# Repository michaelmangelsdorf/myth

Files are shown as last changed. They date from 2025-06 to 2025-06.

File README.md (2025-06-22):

### Intro

This is my successor project to [Sonne8](https://github.com/michaelmangelsdorf/Sonne8), a discrete micro-controller built using about one-hundred 74HC series logic chips, some CMOS memory and passive-components only. It runs about 1 million instructions per second on a four-layer PCB.

A demonstration video in the other repo shows the controller board with a companion I/O-board I designed stacked on top of it.

In the video, it loads a program for multiplying two numbers from a serial EEPROM running a native SPI implementation. It then computes the result and displays it on the I/O boards 7-segment display.

The new project over here will help me explore a specific, stable version of the CPU a little more and write software for it, before developing more hardware.

The schematics have been stripped of everything I thought wasn't essential, so it's a bit easier to read. In other words, although it's possible to load the schematics file into KiCad, its intended use is only for reference.

The C file is also for reference. It shows the intended workings of the CPU. For a more detailed description of this microcontroller read "spec.md".

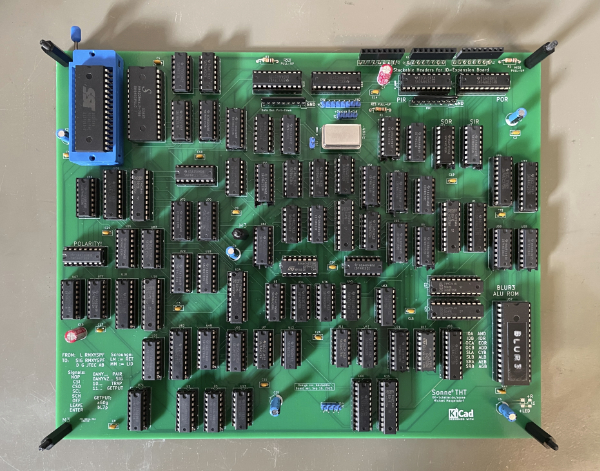
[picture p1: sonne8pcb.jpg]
PCB with working Sonne8 micro-controller


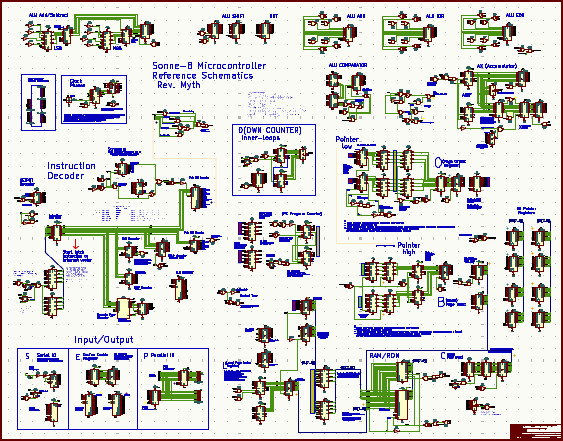
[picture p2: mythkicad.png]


The component count is now higher than for the prototype, because in this project I've implemented the ALU (top and top-right in schematics) in discrete logic, where it used to be just look-up tables in a big PROM.

### Status

There is now a command-line tool (`my`) for exploring Myth. It includes an assembler. The tool is documented in the [specification](https://github.com/michaelmangelsdorf/myth/blob/main/spec.md) file.

### Code Example

Here is an example of a native multiplication routine which multiplies the two 8-bit numbers in the accumulator, leaving the accumulator with the 16-bit result (high-order in A). The listing is the output of the assembler using `my -la`.

    ADDR:  OBJCODE:                  LIN:  SOURCE:
                                     0001  
                                     0002  (Multiply 4x7)
    0000:  84 04 84 07 80 03         0003  fa 4, fa 7 - fc >MUL8. ; Sets A to 7, X to 4 and calls mul8
    0006:  8C 06                     0004  @idle fj <idle         ; my-tool stops at 64k cycles
                                     0005                         ; Check the result using: "my -p"
                                     0006  
                                     0007  ; Multiply A times X, result in A:X
                                     0008  ; A:X accumulator acts as a two-element push-down stack when writing to A
                                     0009  ; Both regs are the implied ALU operands, primary result in A, secondary in X
                                     0010  
                                     0011  ; Using page 3: "my"-tool uses p1 for persisting regs, p2 as IO-buffer
                                     0012  
                                     0013  3@MUL8
    0300:  68                        0014      a1          (Save multiplicand into L1 - turns into low order result)
    0301:  17 6B                     0015      xa a4       (Save multiplier into L4)
    0303:  84 00 69                  0016      fa 0, a2    (Set high-order result to 0, keep in L2)
    0306:  85 07                     0017      fd 7        (Initialise loop counter, 8 bits to process)
                                     0018      @loop
                                     0019          fa b0000_0001, 1a AND  (Check LSB of multiplicand)
    030C:  8E 12                     0020          fz >a                  (Skip if zero)
    030E:  63 61 1D 69               0021              4a 2a ADDC a2      (Add multiplier to high order result)
                                     0022          @a
                                     0023          1a SHR, a1             (Shift low-order result right)
    0315:  61 1B 69                  0024          2a SHR, a2             (Shift high-order result right, LSB saved to X)
    0318:  17 60 15 68               0025          xa 1a IOR, a1          (Carry high-order LSB into low-order MSB)
    031C:  8B 08                     0026      fw <loop
    031E:  60                        0027      1a          (Push low-order result)
    031F:  61                        0028      2a          (Push high-order result)
    0320:  05                        0029      RTS

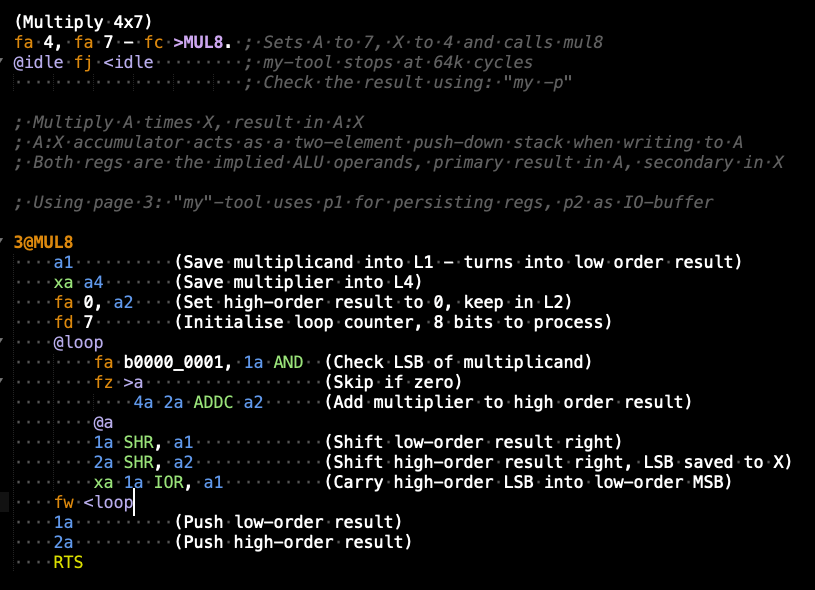
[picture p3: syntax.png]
Source
Source Code  of the multiplication routine in Sublime text with syntax highlighting.

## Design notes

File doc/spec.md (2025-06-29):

## Myth CPU/Micro-Controller
## OVERVIEW

Myth is an educational 8-bit CPU with a reduced, but hopefully enjoyable feature set. It has no microcoded complex instructions, but care has been taken to allow for practicable programming that should be intuitive to the assembler programmer.

The project is based on an earlier prototype, built successfully using just under 100 74HC series chips, some CMOS memory and passive components.

Published schematics and documentation of the earlier project, including the design files for the final PCB production run at JLCPCB are on GitHub:
https://github.com/michaelmangelsdorf/Sonne8

## PART 1

### Basic CPU

#### Power-up and Reset

When the CPU is reset, registers L (stack frame pointer), C (program page index), PC (program offset) and the BUSY flag (disable interrupts) are set to zero, and the first instruction is fetched from address C:PC. PC is then incremented for the next instruction fetch, and so on.

#### Accumulator and ALU

An accumulator with two registers (A and X) feeds into an Arithmetic Logic Unit (ALU), computes a result, then overwrites A and, in some cases, X with the results.

The primary result (the sum of both registers, for instance) is stored in A, the secondary result (carry bit of the sum) is stored in X.

When writing a value into A (instructions _A and GETA), the accumulator functions as a two-element push-down stack: The old value of A is saved into X before overwriting it with the new value. X can be saved into A with the XA instruction.

X cannot be read or written directly.

Here is an example that demonstrates the use of the ALU in conjunction with the accumulator:

    ; F_ fetches a literal and places it into whatever _ is
    
    FA 4  (Pushes 4 onto the accumulator stack AX)
    FA 5  (Pushes 5)
    
    (A is now 5, X is 4)
    
    ADDC  ; Add A and X; secondary result/side effect:
          ; carry bit in X
    
    (A is now 9, X is 0)
    
    SHR   ; Shift A right; secondary result/side effect:
          ; previous low order bit as 0 or 80h in X
    
    (A is now 4, X is 1)
    
    AGX   ; Produce flag: A greater than X, no side effect
    
    (A is FFh - true, X is 1 - unchanged)

The ALU can run the following opcodes:

     0 NOT   Set A to one's complement of A, X unchanged
     1 ALX   Flag (A<X) in A (255 if true, 0 if false), X unchanged
     2 AEX   Flag (A==X) in A (255 if true, 0 if false), X unchanged
     3 AGX   Flag (A>X) in A (255 if true, 0 if false), X unchanged
     4 AND   Set A to (A AND X), X unchanged
     5 IOR   Set A to (A OR X), X unchanged
     6 EOR   Set A to (A XOR X), X unchanged
     7 XA    Set A equal to X, X unchanged
     8 AX    Set X equal to A
     9 SWAP  Swap A and X
    10 SHL   Shift A left, result in A, set X to previous MSB of A as LSB (0 or 1)
    11 SHR   Shift A right logically, result in A, set X to previous LSB of A as MSB (0 or 80h)
    12 ASR   Shift A right arithmetically, set X to previous LSB of A as MSB (0 or 80h)
    13 ADDC  Add A to X, result in A, CARRY bit in X (0 or 1)
    14 ADDV  Add A to X, result in A, OVERFLOW flag in X (255 if OVF, else 0)
    15 SUBB  Subtract A from X, result in A, BORROW bit in X (0 or 1)

#### Memory Layout

Memory is accessed as 256 pages of 256 bytes each (64k).

A memory address is composed of a page index (high order address byte) and an offset (low order address byte) within that page. For example address 0x6502 has a page index of 0x65 and a byte offset of 0x02.

##### Offset Registers

There are only two offset registers and they are the only means of setting address offsets in this design, so must be used for directly accessing memory.

For data memory access, the byte offset in the offset register (O) is used, and the byte offset for fetching instructions and literals is stored in the program counter register (PC).

There are instructions that access memory with implied offsets, however.

##### Page-Index Registers

There are four page-index registers: B for Base, C for Code, K for Key, and L for Local.

###### Register B

For data memory access, the base register (B) is used together with O as the memory pointer to the address where read or write operations occur.

The 16-bit value B:O is called the base pointer. The base pointer is the only means of composing complete 16-bit addresses (pointers) directly.

###### Register C

When code is running, the program counter register (PC) holds the byte offset of the current instruction in memory. The page number where this offset applies is stored in C (Code).

###### Register K

This is an amenity register that can be set to B using the KEY instruction. It is used in conjunction with the PAIR transfer target xK, an effect register. When writing into xK, the written value is stored in O, and B is set to K.

The intended use for this instruction is to provide a shortcut:

    ;Load a system variable (MYVAR) from a table in page 2
    fb 2 KEY (Set key page-index)
    ...
    fk MYVAR ma (Set base pointer to the MYVAR location and read into A)

###### Register L

The purpose of the L (local) page index register is to provide single page stack frames for subroutines. During subroutine calls, the page index in L is decremented, so that memory reads and writes using the L page index transparently access memory which is local to the currently running subroutine. When the subroutine returns, the page index in L is incremented, so that the previous stack frame (or L page) is restored to the calling subroutine.

#### GETPUT Instructions and Stack Frames

Instructions of type GETPUT complement the behaviour explained in the section on L. GETPUT instructions have mnemonics that consist of a digit and a letter. The letter names one of the allowed registers for this type of instruction: B, O, A, or D. The letter is a digit between 1 and 8, used as a short-hand to reference offsets 0xF8 to 0xFF in the local page (page index L). These memory locations are also referred to as L1 to L8. By means of the GETPUT instructions, L1 to L8 become quick-access memory locations that can be used as local variables within the current stack frame.

The position of the digit relative to the letter determines the direction of the data move. For example: 1a transfers the memory content at offset 0xF8 into register A. And d5 transfers register D (down-counter) into memory at offset 0xFC of the local page.

The local-page index can be manually decremented using ENTER, and manually incremented using LEAVE.

#### PAIR Instructions and Effect Registers

Data move instructions of type PAIR have mnemonics that consist of two letters, one for the source, followed by one for the target of the data move. For example, in order to write register B into A, there is an instruction with the mnemonic "ba".

Some registers are "conventional" data registers, such as B and A, which correspond to physical registers, but there are also EFFECT registers, which source or distribute data indirectly, or trigger conditional actions. One of them is the F register (fetch). It extracts the next byte in the instruction stream, and then skips to the next instruction.

Example: "fa" fetches the byte following the current instruction in memory, and stores it into A. It then increments the program counter by 1 so that the next instruction is fetched instead of the literal.

#### Intrapage Control Flow and D Register

Branching inside of the current code page (page index C) is controlled by writing into the five effect registers J (Jump), W (While), H (Hot/Not zero), Z (Zero), or N (Negative).

By writing a branch offset into J, the program counter is set to this new offset without condition. Writing to H loads the PC with the new offset only if register A (Accumulator) is non-zero ("hot"). Writing to Z loads PC with the new offset only if A is zero. W (while) works in conjunction with the D (down-counter) register; when a branch offset is written into W, PC is loaded with the new offset only while/if the D register is non-zero. Then, in either case, the D register is decremented.

#### Interpage Control Flow and TRAP Instructions

On power-up and reset, registers C and PC are set to zero and the first instruction is fetched from address C:PC.

Branching to code in a different page is done by writing into one of the effect registers C (call), by executing a return instruction (RTS or RTI), the COR (coroutine) instruction, or executing a TRAP instruction.

TRAP instructions have immediate opcodes that encode a target page-index for a call. When executed, an implicit subroutine call to this encoded page-index occurs within a single instruction. A TRAP to page 0 sets the BUSY flag and disables interrupts. The BUSY flag is cleared by executing RTI. Trap calls must be left by executing RTI (Return from Interrupt)!, since they are using another pointer (IA) instead of B:O for saving and restoring the return address.

When executing RTS, the code page index register C is loaded with the value in B (base), the program counter register PC is loaded with the value of register O (offset), and the local-page index in register L is incremented.

When executing RTI, the C:PC pair is loaded from the IA amenity pointer, and the local-page index in register L is incremented.

While executing a trap or when writing a target page-index into the effect register C (call), the program counter is set to 0 (!) and the target page index is loaded into C, so that execution in the target page always starts at offset zero, the page "head".

When writing a target page index into C (call), the previous value of C is first saved into B (base), and the value of PC is saved into the O (offset) register before PC is set to zero, so that the called subroutine can save this information in order to return to the caller.

#### PAIR Memory access - Effect Register M

Writing into M (xM) stores the value into memory at page index B offset O. Conversely, reading from M (Mx) transfers the value stored into that memory cell into the target of the PAIR instruction. There are no other memory transfer instructions besides xMx, the GETPUT instructions, and Fx.

#### Scrounged PAIR opcodes

Inherent NOP instructions such as BB, OO, AA, and DD, and impractical instructions such as FM and MM (same-cycle memory load-store) are repurposed ("scrounged"), and their respective opcodes execute different instructions.

	FM routed to: KEY (Copy B into K)
	MM routed to: CODE (set B:O to C:PC)
	BB routed to: LOCAL (set B:O to L:0xF7 - "L0")
	OO routed to: LEAVE (increment L)
	AA routed to: ENTER (decrement L)
	DD routed to: INC (increment A)
	SS routed to: DEC (decrement A)
	PP routed to: EA (Copy E to A)

#### B:O Pointer Register (BOPs) and Amenity Pointers

As mentioned, registers B (base) and O (offset) form a 16-bit pointer for memory access. The xU (update) instruction is used to add an 8-bit signed number to this pointer for doing address arithmetic.

There are four 16-bit amenity registers into which the B:O pointer can be saved, or from which it can be loaded in a single instruction (instruction group BOP). For instance: BOP1 stores the B:O pointer into P1, and P1BO stores P1 into B:O.

The fourth amenity pointer (P4 => IA) is reserved for trap and interrupt operation. See the note on usage conventions for these pointers in the "Programming" section.

#### Interrupts

An external device can make an interrupt request (IRQ) by asserting the IRQ signal.

At the beginning of each instruction cycle, the CPU checks whether an Interrupt must be serviced. There are two conditions which prevent an interrupt from being serviced by the microcontroller during a given instruction cycle. Firstly, when the CPU is running code within page 0, for example just after RESET, and secondly when the BUSY flag is set.

If the BUSY flag is not set, and the page index in C is not zero, the CPU injects a "fake" TRAP call instruction to page 0, instead of fetching a proper instruction opcode. By entering page 0, an interrupt service routine in page zero at address-offset 0 is run.

To re-enable interrupts, the software must execute an RTI instruction (Return from Interrupt). RTI behaves like RTS (Return from Subroutine), but clears the BUSY flag and uses a separate pointer register (IA) to save/restore the return address. As long as the BUSY flag remains set, downstream service routines or other code will not be interrupted by interrupts.

The interrupt service subroutine once it returns resumes execution at the point in code where the interrupt occurred.

You can manually set BUSY by executing TRAP 0. Only this instruction will work, other calls to page 0 do not have this side effect.

## PART 2 - I/O Functionality (Dedicated Registers and Instructions)

#### Device Selection

The CPU can control serial and parallel communication with external components. This is facilitated by dedicated hardware-registers and instructions.

##### E (Enable) register

The 8-bit E register is used to control the select state of devices attached to the serial or parallel bus lines. To this end, the register is divided into two independent four-bit groups for device selection.

Each four-bit group (L for the low-order, H for the high-order) drives a 4-to-16 line decoder, which maps the bit pattern encoded by that group to 1 of 16 possible, mutually exclusive select signals (SL0-15 and SH0-15) per group.

###### Special Purpose Selectors

Select signals SL0 and SH0 are reserved, and select a NULL device ("nothing"). These signals are selected on power-up or reset.

SL1 corresponds to the internal POR register output enable signal (POE). SH1 corresponds to the internal PIR register latch enable signal (PLE).

In order to latch the current value of the GPIO bus into the PIR, the PLE signal must be set by the high-order nybble of E. Selecting the POE signal by the low-order nybble of E enables the output of the POR register onto the GPIO bus.

All remaining selectors can be used freely.

#### Communication Registers

SOR (Serial Output Register)

A write-only parallel-to-serial shift register for serialising an output byte, modelled after a 74HC165 chip. Writing an output value for serialisation is done by writing the value into register S.

This value is clocked out/serialized by pulsing the SCLK clock line. This is achieved by alternating SCL and SCH instructions (set clock low/high).

SCL-SCH-SCL generates a positive clock edge. SCH-SCL-SCH generates an inverted clock. Eight clock cycles are required to send-out a byte.

SIR (Serial Input Register)

A read-only serial-to-parallel shift register for de-serialising an incoming bit stream into an input byte, modelled after a 74HC595 chip.

Receiving a byte is done by executing the SCL/SCH instructions eight times as explained above. Reading the deserialised input byte is done by reading register S.

POR (Parallel Output Register)

A tri-state register with 8-bit parallel output, modelled after a 74HC574 chip. Writing an output byte onto the parallel bus is a two step process. First, the data byte must be latched into the register by writing it into P. Then, the register output must be enabled by selecting POE in the E register, as described above.

PIR (Parallel Input Register)

A read-only 8-bit parallel input register, modelled after a 74HC574 chip. Latching the current 8-bit value of the parallel bus into the register is done by selecting PLE in E. The latched data byte can then be read from P. The bus operates in weak pull-down mode, so when all bus-devices are in tri-state mode, a zero value is registered.

#### Communication Instructions

#### SERIAL

The following instructions contained in the SYS group operate on the communication registers:

SSI (Shift Serial In)

This instruction receives a serial bit via the serial input line. It then shifts SIR left and sets its least significant bit (LSB) to the received bit state.

SSO (Shift Serial Out)

This instruction outputs the most significant bit (MSB) of SOR onto the serial output line and then shifts SOR left.

SCH (Serial clock high)

This instruction sets the clock line to HIGH.

SCL (Serial clock low)

This instruction sets the clock line to LOW.

#### PARALLEL

The CPU interfaces to an external bidirectional 8-bit wide bus (GPIO bus).

It can communicate on this bus by writing a data byte into P (POR register), and then enabling POE in the E register by setting its lower nybble to 1. Setting the bit to 1 switches the POR from tri-state output to active output, so that the byte value is output on the bus lines.

While the output is active, other devices on the bus can read the data byte. Usually, such a device will be controlled or synchronised by the Myth controller. It does this by enabling or disabling latches or outputs of the required device in E as explained above. This generates output signals made available to external devices on the micro-controller pins. Exactly two output signals (one per nybble in E) can be active at the same time.

Deselecting POE in E again (setting the low-order nybble to a value different from 1) tristates the POR output, so that other devices can put data bytes on the GPIO bus.

Enabling PLE in E (setting the high-order nybble to 1) latches a data byte into the PIR. This byte can then be read from the P register.

Once a data byte has been read, the PIR input should be deselected again in E by setting the high-order nybble to a value different from 1.

### Serial Communication

The Serial Peripheral Interface (SPI) protocol can be implemented using the device enable register E, serial registers SIR and SOR, and instructions SCL, SCH, SSI, and SSO.

#### Device Selection

Before communicating with a specific device connected to the serial bus, the corresponding se<lector bit representing the device must be set in the E register.

#### Data Transmission

To transmit data to the selected device, the processor writes a data byte (8 bits) to be serialised for output into the SOR (Serial Output) register.

The SSO (Serial Shift Out) instruction is then used, which clocks the serial output shift register and produces a data bit on the MOSI line. Using the instruction sequence SCL SCH SCL (Serial Clock Low/High), a positive edge clock pulse is generated.

As each bit is shifted out, it is sent to the selected device through the serial bus. The passive device processes the transmitted bit and the cycle repeats.

#### Data Reception

To receive data from an external device, the SSI (Serial Shift In) instruction is used. It clocks the serial input shift register, allowing the processor to receive one bit of data at a time from the selected device via the MISO line. The received data can then be read from the S register. Clocking is done as above.

##### CPOL (Clock Polarity)

The CPOL parameter determines the idle state of the clock signal. The controller provides signals SCL (Serial Clock Low) and SCH (Serial Clock High) instructions which can be used to control the clock signal's state.

To configure CPOL=0 (clock idles low), execute SCL to set the clock signal low during the idle state. To configure CPOL=1 (clock idles high), execute SCH to set the clock signal high during the idle state.

##### CPHA (Clock Phase)

The CPHA parameter determines the edge of the clock signal where data is captured or changed. The Myth controller provides instructions SSI (Serial shift in) and SSO (Serial shift out) to control data transfer on each clock transition.

To configure CPHA=0 (data captured on the leading edge), execute SSI before the clock transition to capture the incoming data. To configure CPHA=1 (data captured on the trailing edge), execute SSI after the clock transition to capture the incoming data.

Similarly, to transmit data on the leading or trailing edge, execute SSO before or after the clock transition, respectively.

#### Device Deselection

After data transmission is complete, the selected device needs to be deselected to allow other devices to communicate on the bus. This is done by updating the E register with the appropriate value.

## Part 3 - Programming

### Opcode Format

Operation codes fall into 6 format groups, which are decodable using a priority encoder. 

                      -- Opcode Bits --
                         MSB     LSB
    all 0: OPC_SYS       00000   xxx    See table @ SYS decoder
     else: OPC_BOP       00001   xxx    See table @ BOP decoder
           OPC_ALU       0001   xxxx    See table @ ALU
           OPC_TRAP      001   xxxxx    b0-4: DESTPAGE
           OPC_GETPUT    01 xx x xxx    b0-2: OFFS, b3: GET/PUT, b4-5: REG
           OPC_PAIR      1  xxx xxxx    b0-3: DST, b4-6: SRC

### Assembler

#### Labels

- Address labels are defined using identifiers prefixed with an at-sign (`@labelname`). A decimal number before the at sign (`123@labelname`) sets the page-index for emitting object code to that number, if the labelname is all-uppercase, or sets the page-offset to that number if the labelname contains lowercase letters.
- A label may optionally be followed by a colon (`:`), like `@FOO:` — this marks it as a **global label**. Global labels are inserted into the **native symbol table** (inside the resulting binary image).
- Labels must be unique **unless** they are a **single lowercase letter** (`@a`, `@b`, etc.), which may be defined multiple times (for generic labels such as short jumps). When defined multiple times, the nearest matching label in either direction will be used, see below.

#### Label References

- Use `<label` for a **backward reference** to the closest matching label earlier in the file.
- Use `>label` for a **forward reference** to the closest matching label later in the file.
- Use `#label` for a general, first-match search.

#### Trap Call Syntax

- The asterisk is used for trap call references: `*label` or `*123`, or `*1Fh` etc. all assemble trap instructions.

#### Constants (Data Labels)

- You can define a constant using `name=value`. The value can be any valid number literal (see below).
- Defined constants can be used later by referencing their name in the source code.
- A colon after the label name (`name:=value`) defines a global label.

#### Special Tokens

- `PAGE` — Page-index of the current instruction.
- `OFFSET` — Page-offset of the current instruction.

#### Literals

- **Decimal**: e.g., `42`, `-5`
- **Hexadecimal**: Suffix `h` (e.g., `2Ah`, `0FFh`)
- **Binary**: Prefix `b`, underscores allowed (e.g., `b1010_0001`)
- **Character literal**: Single character in quotes (e.g., `'A'`)
- **String literal**: Double quotes, may contain spaces (e.g., `" hello world "`)

#### Mnemonics

- Mnemonics are case insensitive — `addc`, `ADDC`, and `AddC` are all valid.
- Example mnemonics: `AND`, `ADDC`, `RET`, `2r`

#### Comments

- Any text after a semicolon (`;`) is a comment.
- Text enclosed in parentheses `(A comment)` is also treated as a comment — including the parentheses themselves. Useful for commenting out just one or two mnemonics.

#### Phrasing

Any assembly token can be followed by a comma (,) or a dot (.), and dashes are ignored.

    fa 1, fa 2 (pushed onto A) - ADDC. ; These are fine

#### Syntax-Highlighting in Sublime

Place the syntax and color scheme definition files from the repo inside the folder: `/Users/???/Library/Application Support/Sublime Text 3/Packages/User'` (macOS).

Then in Sublime, press CMD-Shift-P. In the dialog, navigate to: `Preferences: Settings- Syntax Specific` and paste the following snippet.
 
    // These settings override both User and Default settings for the myth-my8 syntax
    {
    	// Sets the colors used within the text area.
    	// The value "auto" will switch between the "light_color_scheme" and
    	// "dark_color_scheme" based on the operating system appearance.
    	"color_scheme": "myth-dark-my8.sublime-color-scheme"
    }

There is also a light theme (`myth-light-my8.sublime-color-scheme`) in the repo.

### "My"-Tool for Native  Development

The command line tool `my` (for Myth) can be used to set registers, print memory read-outs, and for assembling and running assembler code. The source-code for `my` is in the `util` folder of the Myth GitHub repo.

On each invocation, the program reads in a complete 64k RAM image (default name: `ram.bin` that is used as memory for a virtual Myth CPU. You can create this file by running `my -N <filename>`. Before the tool terminates, the (possibly modified) RAM is persisted back into the image file.

You can assemble a source file into this image with `my -la <filename>`. The `l` option in this example prints an additional assembly listing including the emitted object code by source line.

A memory read-out (dump) can be printed out with `my -b 2 -d 2000h`. This example prints 16 data bytes stored starting at address 0x2000, listing them in three number bases. See `my -h` for more options.

You can set individual CPU registers using `my -w regname=value`. The command `my -p` prints out a text block of all registers ("pulley").

Individual instructions can be executed with `my -o mnemonic`, and the virtual CPU can be instructed to run n cycles with `my -r n` (for single-step only use `my -s`). Be mindful of setting C and PC to suitable values!

There is a special dialog mode, when `my` is run with a command line where the first character is not a '-' (not a command line option). The command line (max 127 ascii bytes) is then copied into the RAM image at 0x2100 and the CPU is run in order to have it write an output string (max 127 bytes) at 0x2180. The CPU is stopped and the tool terminates as soon as the output string becomes not NULL, or once 64k cycles have elapsed. You can then run `my -m` to try for another 64k cycles.

Example `my` session:

The example sets the accumulator registers A and X, and executes the ADDC instruction, which produces the sum of A and X in A, and the carry generated by the addition into X.

    (base) ➜  myth-tool git:(main) ✗ my -p
    
    C:00 PC:A7          E:00(0000_0000) E_OLD:00(0000_0000)
    SCLK:0 MISO:0 MOSI:0      SIR:00 SOR:00   PIR:00 POR:00
    A:09(+009,0000_1001)  X:00(+000,0000_0000)   D:00  L:00
    BO:0000  P1:0000 P2:0000 P3:0000 P4:0000   KEY:00 L0:00
    L1:00(+000) L2:00(+000) L3:00(+000) L4:00(+000)   IRQ:0
    L5:00(+000) L6:00(+000) L7:00(+000) L8:00(+000)  BUSY:0
    
    (base) ➜  myth-tool git:(main) ✗ my -w a=4
    (base) ➜  myth-tool git:(main) ✗ my -w x=253
    (base) ➜  myth-tool git:(main) ✗ my -p
    
    C:00 PC:A7          E:00(0000_0000) E_OLD:00(0000_0000)
    SCLK:0 MISO:0 MOSI:0      SIR:00 SOR:00   PIR:00 POR:00
    A:04(+004,0000_0100)  X:FD(-003,1111_1101)   D:00  L:00
    BO:0000  P1:0000 P2:0000 P3:0000 P4:0000   KEY:00 L0:00
    L1:00(+000) L2:00(+000) L3:00(+000) L4:00(+000)   IRQ:0
    L5:00(+000) L6:00(+000) L7:00(+000) L8:00(+000)  BUSY:0
    
    (base) ➜  myth-tool git:(main) ✗ my -o ADDC
    (base) ➜  myth-tool git:(main) ✗ my -p
    
    C:00 PC:A7          E:00(0000_0000) E_OLD:00(0000_0000)
    SCLK:0 MISO:0 MOSI:0      SIR:00 SOR:00   PIR:00 POR:00
    A:01(+001,0000_0001)  X:01(+001,0000_0001)   D:00  L:00
    BO:0000  P1:0000 P2:0000 P3:0000 P4:0000   KEY:00 L0:00
    L1:00(+000) L2:00(+000) L3:00(+000) L4:00(+000)   IRQ:0
    L5:00(+000) L6:00(+000) L7:00(+000) L8:00(+000)  BUSY:0

### Preliminary ROM image ("Firmware")

#### Reserved Pages for My-Tool

##### Page 0 - Interrupts

Due to how interrupts work, code execution after power-on, reset or when an interrupt request is accepted, starts at address 0h. Page 0 should be reserved for handling these various cases, particularly the main interrupt service handler.

##### Pages 1-31 Trap Handlers

The TRAP instruction (*n) is a single-instruction subroutine call to an immediate address encoded in the opcode using 5 bits. The range of call target pages is therefore 0..31. Trap 0 is equivalent to causing an interrupt to happen: doing this calls page 0 and sets the BUSY flag.

##### Page 32 (2000h) - Register Store

My-Tool persists the CPU registers in the 64k firmware image starting at page index 32, address 2000h (see my-tool project files), with the whole page being reserved.

##### Page 33 (2100h) - Text Buffers

Further, page 33 is used for two text buffers which my-tool used to communicate with the Myth VM: In dialog mode, a maximum of 127 bytes of the command line text is stored as a zero terminated string at address 2100h (input buffer). The VM is expected to respond by writing a zero terminated string not exceeding 127 characters into the output buffer at address 2180h.

The first byte of the output buffer should be monitored; when it becomes non-zero, this is a termination/ready signal from the VM. This implies that the output string should be written, with the first character last, overwriting the initial zero at 2180h put there by My-Tool before running the VM.

##### Page 34 (2200h) - Key

The firmware currently sets K to page 34, so that xK instructions set the B:O pointer to 34:x. The xK instruction was implemented to have quick access to one "key" page of frequently used system variables.

(A table of these will be maintained here)

##### Page 35 (2300h) - Stack and P3 Pointer

The amenity pointer P3 is currently reserved as a system wide stack pointer, which serves as parameter stack pointer and threading token pointer, and it is set to 23FFh, growing towards lower addresses. If your routines use it for other purposes, you should restore its value on return.

##### Page 36 (2400h) - Threading Stack

Amenity pointer P2 is currently reserved as a system wide threading stack pointer, set to 24FFh.

P1 can be used as a scratch register for the base pointer (P:O).

#### Other Points

- **Local Page Frames**
Be aware that the local frame pointer in L decrements during subroutine nesting. Subroutines use the highest 9 bytes (F7h - FFh) for local variables L0-L8. The address of L0 is loaded into B:O by the LOCAL instruction. L1-L8 are accessible using GETPUT-instructions. In principal, the whole local page is available to the currently running subroutine. This implies a tradeoff between how much data you store in your local frames, and how long your subroutines are since they must stay clear of the local storage.

- **Threaded Code**
This is particular the firmware, but the subroutines implementing threaded code will use 80h as the implied page offset for interpreter-called code.

#### Symbol Table

The assembler outputs a "Global" symbol table. Entries in this table are formed as follows:

- **Link-Byte**: Relative byte offset to the next entry, or zero for end-of-table.
- **Info-Byte**: High-order nybble encodes the symbol type, low order is the length in bytes of the symbol name -1; hence a maximum length of 16.
- **Name-String** Name of the symbol
- **Zero**: Zero for string termination of the name string
- **Data-Bytes**: Variable number of data-bytes, corresponding to the type of the symbol

The following types are currently used:

- **Assembly label**: Type=1, data-bytes: none
- **Mnemonic**: Type=2, data-bytes: opcode

### Debugging Native Code

Don't forget that you can place hooks directly into cpu.c for instance. As a temporary debugging aid, writing into E (_E) is caught in cpu.c und causes My-Tool to print-out a register dump.

### Parameter passing

Use the accumulator (AX) for primary arguments in general.

There is a "hidden" local variable shortcut "L0". You can obtain a pointer to this memory location by executing the instruction "LOCAL". Local sets B to the Local page, and O to F7h, the byte offset just below L1. Then use MxM instructions such as "am" to read or store into the L0 variable:

    ; Store number 4 in L0:
    (fa 2 shl,) local am.

## Tables

### Opcode Matrix

           x0    x1    x2    x3    x4    x5    x6    x7    x8    x9    xA    xB    xC    xD    xE    xF
    0x    NOP   SSI   SSO   SCL   SCH   RTS   RTI   COR  P1BO  BOP1  P2BO  BOP2  P3BO  BOP3  IABO  BOIA
    1x    NOT   ALX   AEX   AGX   AND   IOR   EOR    XA    AX  SWAP   SHL   SHR   ASR  ADDC  ADDV  SUBB
    2x     *0    *1    *2    *3    *4    *5    *6    *7    *8    *9   *10   *11   *12   *13   *14   *15
    3x    *16   *17   *18   *19   *20   *21   *22   *23   *24   *25   *26   *27   *28   *29   *30   *31
    4x     1b    2b    3b    4b    5b    6b    7b    8b    b1    b2    b3    b4    b5    b6    b7    b8
    5x     1o    2o    3o    4o    5o    6o    7o    8o    o1    o2    o3    o4    o5    o6    o7    o8
    6x     1a    2a    3a    4a    5a    6a    7a    8a    a1    a2    a3    a4    a5    a6    a7    a8
    7x     1d    2d    3d    4d    5d    6d    7d    8d    d1    d2    d3    d4    d5    d6    d7    d8
    8x     fc   KEY    fb    fo    fa    fd    fs    fp    fe    fk    fu    fw    fj    fh    fz    fn
    9x     mc  CODE    mb    mo    ma    md    ms    mp    me    mk    mu    mw    mj    mh    mz    mn
    Ax     bc    bm LOCAL    bo    ba    bd    bs    bp    be    bk    bu    bw    bj    bh    bz    bn
    Bx     oc    om    ob LEAVE    oa    od    os    op    oe    ok    ou    ow    oj    oh    oz    on
    Cx     ac    am    ab    ao ENTER    ad    as    ap    ae    ak    au    aw    aj    ah    az    an
    Dx     dc    dm    db    do    da   INC    ds    dp    de    dk    du    dw    dj    dh    dz    dn
    Ex     sc    sm    sb    so    sa    sd   DEC    sp    se    sk    su    sw    sj    sh    sz    sn
    Fx     pc    pm    pb    po    pa    pd    ps    EA    pe    pk    pu    pw    pj    ph    pz    pn

### Opcode Descriptions

    Group SYS
    
    0x00: NOP	Pass the turn (no operation)
    0x01: SSI	Shift serial bit in
    0x02: SSO	Shift serial bit out
    0x03: SCL	Set serial clock low
    0x04: SCH	Set serial clock high
    0x05: RTS	Return from subroutine
    0x06: RTI	Return from interrupt
    0x07: COR	Coroutine Jump
    
    Group BOP
    
    0x08: P1BO	Copy pointer P1 into B:O
    0x09: BOP1	Copy B:O into pointer P1
    
    0x0A: P2BO	Copy pointer P2 into B:O
    0x0B: BOP2	Copy B:O into pointer P2
    
    0x0C: P3BO	Copy pointer P3 into B:O
    0x0D: BOP3	Copy B:O into pointer P3
    
    0x0E: IABO	Copy pointer IA into B:O
    0x0F: BOIA	Copy B:O into pointer IA
    
    Group ALU
    
    0x10: NOT	Set A to one's complement of A , X unchanged
    0x11: ALX	Flag (A<X) in A (255 if true, 0 if false), X unchanged
    0x12: AEX	Flag (A==X) in A (255 if true, 0 if false), X unchanged
    0x13: AGX	Flag (A>X) in A (255 if true, 0 if false), X unchanged
    0x14: AND	Set A to (A AND X), X unchanged
    0x15: IOR	Set A to (A OR X), X unchanged
    0x16: EOR	Set A to (A XOR X), X unchanged
    0x17: XA	Set A equal to X, X unchanged
    0x18: AX	Set X equal to A
    0x19: SWAP	Swap A and X
    0x1A: SHL	Shift A left, result in A, set X to previous MSB of A as LSB (0 or 1)
    0x1B: SHR	Shift A right logically, result in A, set X to previous LSB of A as MSB (0 or 80h)
    0x1C: ASR	Shift A right arithmetically, set X to previous LSB of A as MSB (0 or 80h)
    0x1D: ADDC	Add A to X, result in A, CARRY bit in X (0 or 1)
    0x1E: ADDV	Add A to X, result in A, OVERFLOW flag in X (255 if OVF, else 0)
    0x1F: SUBB	Subtract A from X, result in A, BORROW bit in X (0 or 1)
    
    Group TRAP
    
    0x20: *0	Trap call to page 0, offset 0 - Set BUSY flag
    0x21: *1	Trap call to page 1, offset 0
    0x22: *2	Trap call to page 2, offset 0
    0x23: *3	Trap call to page 3, offset 0
    0x24: *4	Trap call to page 4, offset 0
    0x25: *5	Trap call to page 5, offset 0
    0x26: *6	Trap call to page 6, offset 0
    0x27: *7	Trap call to page 7, offset 0
    0x28: *8	Trap call to page 8, offset 0
    0x29: *9	Trap call to page 9, offset 0
    0x2A: *10	Trap call to page 10, offset 0
    0x2B: *11	Trap call to page 11, offset 0
    0x2C: *12	Trap call to page 12, offset 0
    0x2D: *13	Trap call to page 13, offset 0
    0x2E: *14	Trap call to page 14, offset 0
    0x2F: *15	Trap call to page 15, offset 0
    0x30: *16	Trap call to page 16, offset 0
    0x31: *17	Trap call to page 17, offset 0
    0x32: *18	Trap call to page 18, offset 0
    0x33: *19	Trap call to page 19, offset 0
    0x34: *20	Trap call to page 20, offset 0
    0x35: *21	Trap call to page 21, offset 0
    0x36: *22	Trap call to page 22, offset 0
    0x37: *23	Trap call to page 23, offset 0
    0x38: *24	Trap call to page 24, offset 0
    0x39: *25	Trap call to page 25, offset 0
    0x3A: *26	Trap call to page 26, offset 0
    0x3B: *27	Trap call to page 27, offset 0
    0x3C: *28	Trap call to page 28, offset 0
    0x3D: *29	Trap call to page 29, offset 0
    0x3E: *30	Trap call to page 30, offset 0
    0x3F: *31	Trap call to page 31, offset 0
    
    Group GETPUT
    
    0x40: 1b	Load B from L1 (M[L:F8h])
    0x41: 2b	Load B from L2 (M[L:F9h])
    0x42: 3b	Load B from L3 (M[L:FAh])
    0x43: 4b	Load B from L4 (M[L:FBh])
    0x44: 5b	Load B from L5 (M[L:FCh])
    0x45: 6b	Load B from L6 (M[L:FDh])
    0x46: 7b	Load B from L7 (M[L:FEh])
    0x47: 8b	Load B from L8 (M[L:FFh])
    
    0x48: b1	Store B into L1 (M[L:F8h])
    0x49: b2	Store B into L2 (M[L:F9h])
    0x4A: b3	Store B into L3 (M[L:FAh])
    0x4B: b4	Store B into L4 (M[L:FBh])
    0x4C: b5	Store B into L5 (M[L:FCh])
    0x4D: b6	Store B into L6 (M[L:FDh])
    0x4E: b7	Store B into L7 (M[L:FEh])
    0x4F: b8	Store B into L8 (M[L:FFh])
    
    0x50: 1o	Load O from L1 (M[L:F8h])
    0x51: 2o	Load O from L2 (M[L:F9h])
    0x52: 3o	Load O from L3 (M[L:FAh])
    0x53: 4o	Load O from L4 (M[L:FBh])
    0x54: 5o	Load O from L5 (M[L:FCh])
    0x55: 6o	Load O from L6 (M[L:FDh])
    0x56: 7o	Load O from L7 (M[L:FEh])
    0x57: 8o	Load O from L8 (M[L:FFh])
    
    0x58: o1	Store O into L1 (M[L:F8h])
    0x59: o2	Store O into L2 (M[L:F9h])
    0x5A: o3	Store O into L3 (M[L:FAh])
    0x5B: o4	Store O into L4 (M[L:FBh])
    0x5C: o5	Store O into L5 (M[L:FCh])
    0x5D: o6	Store O into L6 (M[L:FDh])
    0x5E: o7	Store O into L7 (M[L:FEh])
    0x5F: o8	Store O into L8 (M[L:FFh])
    
    0x60: 1a	Load A from L1 (M[L:F8h])
    0x61: 2a	Load A from L2 (M[L:F9h])
    0x62: 3a	Load A from L3 (M[L:FAh])
    0x63: 4a	Load A from L4 (M[L:FBh])
    0x64: 5a	Load A from L5 (M[L:FCh])
    0x65: 6a	Load A from L6 (M[L:FDh])
    0x66: 7a	Load A from L7 (M[L:FEh])
    0x67: 8a	Load A from L8 (M[L:FFh])
    
    0x68: a1	Store A into L1 (M[L:F8h])
    0x69: a2	Store A into L2 (M[L:F9h])
    0x6A: a3	Store A into L3 (M[L:FAh])
    0x6B: a4	Store A into L4 (M[L:FBh])
    0x6C: a5	Store A into L5 (M[L:FCh])
    0x6D: a6	Store A into L6 (M[L:FDh])
    0x6E: a7	Store A into L7 (M[L:FEh])
    0x6F: a8	Store A into L8 (M[L:FFh])
    
    0x70: 1d	Load D from L1 (M[L:F8h])
    0x71: 2d	Load D from L2 (M[L:F9h])
    0x72: 3d	Load D from L3 (M[L:FAh])
    0x73: 4d	Load D from L4 (M[L:FBh])
    0x74: 5d	Load D from L5 (M[L:FCh])
    0x75: 6d	Load D from L6 (M[L:FDh])
    0x76: 7d	Load D from L7 (M[L:FEh])
    0x77: 8d	Load D from L8 (M[L:FFh])
    
    0x78: d1	Store D into L1 (M[L:F8h])
    0x79: d2	Store D into L2 (M[L:F9h])
    0x7A: d3	Store D into L3 (M[L:FAh])
    0x7B: d4	Store D into L4 (M[L:FBh])
    0x7C: d5	Store D into L5 (M[L:FCh])
    0x7D: d6	Store D into L6 (M[L:FDh])
    0x7E: d7	Store D into L7 (M[L:FEh])
    0x7F: d8	Store D into L8 (M[L:FFh])
    
    Group PAIR
    
    0x80: FC	Take M[C:PC++] as page-index, load the index into C, set PC to 0. Save return pointer into B:O. Decrement L
    0x81: KEY	Copy register B into K
    0x82: FB	Take M[C:PC++] into B
    0x83: FO	Take M[C:PC++] into O
    0x84: FA	Push M[C:PC++] into Acc
    0x85: FD	Take M[C:PC++] into D
    0x86: FS	Take M[C:PC++] into SOR
    0x87: FP	Take M[C:PC++] into POR
    0x88: FE	Take M[C:PC++] into E, sets device enable signals
    0x89: FK	Take M[C:PC++] into O, load K into B
    0x8A: FU	Take M[C:PC++] as 8-bit signed number and add it to 16-bit pointer B:O
    0x8B: FW	Take M[C:PC++] as page offset and store it into PC - while register D is not zero. In either case, decrement D
    0x8C: FJ	Take M[C:PC++] as page offset and store it into PC - always
    0x8D: FH	Take M[C:PC++] as page offset and store it into PC - if A is not equal to zero
    0x8E: FZ	Take M[C:PC++] as page offset and store it into PC - if A is equal to zero
    0x8F: FN	Take M[C:PC++] as page offset and store it into PC - if A is negative (has bit 7 set)
    
    0x90: MC	Take M[B:O] as page-index, load the index into C, set PC to 0. Save return pointer into B:O. Decrement L
    0x91: CODE	Copy pointer C:PC into B:O
    0x92: MB	Take M[B:O] into B
    0x93: MO	Take M[B:O] into O
    0x94: MA	Push M[B:O] into Acc
    0x95: MD	Take M[B:O] into D
    0x96: MS	Take M[B:O] into SOR
    0x97: MP	Take M[B:O] into POR
    0x98: ME	Take M[B:O] into E, sets device enable signals
    0x99: MK	Take M[B:O] into O, load K into B
    0x9A: MU	Take M[B:O] as 8-bit signed number and add it to 16-bit pointer B:O
    0x9B: MW	Take M[B:O] as page offset and store it into PC - while register D is not zero. In either case, decrement D
    0x9C: MJ	Take M[B:O] as page offset and store it into PC - always
    0x9D: MH	Take M[B:O] as page offset and store it into PC - if A is not equal to zero
    0x9E: MZ	Take M[B:O] as page offset and store it into PC - if A is equal to zero
    0x9F: MN	Take M[B:O] as page offset and store it into PC - if A is negative (has bit 7 set)
    
    0xA0: BC	Take B as page-index, load the index into C, set PC to 0. Save return pointer into B:O. Decrement L
    0xA1: BM	Take B into M[B:O]
    0xA2: LOCAL	Copy pointer L:F7h (L0) into B:O
    0xA3: BO	Take B into O
    0xA4: BA	PushB into Acc
    0xA5: BD	Take B into D
    0xA6: BS	Take B into SOR
    0xA7: BP	Take B into POR
    0xA8: BE	Take B into E, sets device enable signals
    0xA9: BK	Take B into O, load K into B
    0xAA: BU	Take B as 8-bit signed number and add it to 16-bit pointer B:O
    0xAB: BW	Take B as page offset and store it into PC - while register D is not zero. In either case, decrement D
    0xAC: BJ	Take B as page offset and store it into PC - always
    0xAD: BH	Take B as page offset and store it into PC - if A is not equal to zero
    0xAE: BZ	Take B as page offset and store it into PC - if A is equal to zero
    0xAF: BN	Take B as page offset and store it into PC - if A is negative (has bit 7 set)
    
    0xB0: OC	Take O as page-index, load the index into C, set PC to 0. Save return pointer into B:O. Decrement L
    0xB1: OM	Take O into M[B:O]
    0xB2: OB	Take O into B
    0xB3: LEAVE	Increment L
    0xB4: OA	Push O into Acc
    0xB5: OD	Take O into D
    0xB6: OS	Take O into SOR
    0xB7: OP	Take O into POR
    0xB8: OE	Take O into E, sets device enable signals
    0xB9: OK	Take O into O, load K into B
    0xBA: OU	Take O as 8-bit signed number and add it to 16-bit pointer B:O
    0xBB: OW	Take O as page offset and store it into PC - while register D is not zero. In either case, decrement D
    0xBC: OJ	Take O as page offset and store it into PC - always
    0xBD: OH	Take O as page offset and store it into PC - if A is not equal to zero
    0xBE: OZ	Take O as page offset and store it into PC - if A is equal to zero
    0xBF: ON	Take O as page offset and store it into PC - if A is negative (has bit 7 set)
    
    0xC0: AC	Take A as page-index, load the index into C, set PC to 0. Save return pointer into B:O. Decrement L
    0xC1: AM	Take A into M[B:O]
    0xC2: AB	Take A into B
    0xC3: AO	Take A into O
    0xC4: ENTER	Decrement L
    0xC5: AD	Take A into D
    0xC6: AS	Take A into SOR
    0xC7: AP	Take A into POR
    0xC8: AE	Take A into E, sets device enable signals
    0xC9: AK	Take A into O, load K into B
    0xCA: AU	Take A as 8-bit signed number and add it to 16-bit pointer B:O
    0xCB: AW	Take A as page offset and store it into PC - while register D is not zero. In either case, decrement D
    0xCC: AJ	Take A as page offset and store it into PC - always
    0xCD: AH	Take A as page offset and store it into PC - if A is not equal to zero
    0xCE: AZ	Take A as page offset and store it into PC - if A is equal to zero
    0xCF: AN	Take A as page offset and store it into PC - if A is negative (has bit 7 set)
    
    0xD0: DC	Take D as page-index, load the index into C, set PC to 0. Save return pointer into B:O. Decrement L
    0xD1: DM	Take D into M[B:O]
    0xD2: DB	Take D into B
    0xD3: DO	Take D into O
    0xD4: DA	Push D into Acc
    0xD5: INC	Increment A
    0xD6: DS	Take D into SOR
    0xD7: DP	Take D into POR
    0xD8: DE	Take D into E, sets device enable signals
    0xD9: DK	Take D into O, load K into B
    0xDA: DU	Take D as 8-bit signed number and add it to 16-bit pointer B:O
    0xDB: DW	Take D as page offset and store it into PC - while register D is not zero. In either case, decrement D
    0xDC: DJ	Take D as page offset and store it into PC - always
    0xDD: DH	Take D as page offset and store it into PC - if A is not equal to zero
    0xDE: DZ	Take D as page offset and store it into PC - if A is equal to zero
    0xDF: DN	Take D as page offset and store it into PC - if A is negative (has bit 7 set)
    
    0xE0: SC	Take SIR as page-index, load the index into C, set PC to 0. Save return pointer into B:O. Decrement L
    0xE1: SM	Take SIR into M[B:O]
    0xE2: SB	Take SIR into B
    0xE3: SO	Take SIR into O
    0xE4: SA	Push SIR into Acc
    0xE5: SD	Take SIR into D
    0xE6: DEC	Decrement A
    0xE7: SP	Take SIR into POR
    0xE8: SE	Take SIR into E, sets device enable signals
    0xE9: SK	Take SIR into O, load K into B
    0xEA: SU	Take SIR as 8-bit signed number and add it to 16-bit pointer B:O
    0xEB: SW	Take SIR as page offset and store it into PC - while register D is not zero. In either case, decrement D
    0xEC: SJ	Take SIR as page offset and store it into PC - always
    0xED: SH	Take SIR as page offset and store it into PC - if A is not equal to zero
    0xEE: SZ	Take SIR as page offset and store it into PC - if A is equal to zero
    0xEF: SN	Take SIR as page offset and store it into PC - if A is negative (has bit 7 set)
    
    0xF0: PC	Take PIR as page-index, load the index into C, set PC to 0. Save return pointer into B:O. Decrement L
    0xF1: PM	Take PIR into M[B:O]
    0xF2: PB	Take PIR into B
    0xF3: PO	Take PIR into O
    0xF4: PA	Push PIR into Acc
    0xF5: PD	Take PIR into D
    0xF6: PS	Take PIR into SOR
    0xF7: EA	Push E into Acc
    0xF8: PE	Take PIR into E, sets device enable signals
    0xF9: PK	Take PIR into O, load K into B
    0xFA: PU	Take PIR as 8-bit signed number and add it to 16-bit pointer B:O
    0xFB: PW	Take PIR as page offset and store it into PC - while register D is not zero. In either case, decrement D
    0xFC: PJ	Take PIR as page offset and store it into PC - always
    0xFD: PH	Take PIR as page offset and store it into PC - if A is not equal to zero
    0xFE: PZ	Take PIR as page offset and store it into PC - if A is equal to zero
    0xFF: PN	Take PIR as page offset and store it into PC - if A is negative (has bit 7 set)
    (base) ➜  mystuff git:(main) ✗ clang opcode_details.c
    (base) ➜  mystuff git:(main) ✗ a.out

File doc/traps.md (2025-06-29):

### Traps

Trap instructions are single-cycle subroutine calls. There are 32 of them, and they all do the same thing, with just a different address.

They act like instruction set extensions, because it's completely up to you to decide what happens, when their opcodes are executed.

You may or may not know this, but below what is called machine-code, many computers have another layer of even more primitive instructions, called microcode. The regular machine-code instructions are built from these microcode instructions, that tell the hardware exactly how the (macro-)instruction must perform.

So when you normally program in assembler, with each instruction, you are actually running a little microcode program.

The Myth computer is really primitive, so that it took fewer components to build it. It's instructions are actually microcode.

And the idea with implementing trap instructions was that you then have 32 free opcodes to implement more complex custom instructions in the form of single-byte subroutine calls.

A trap instruction opcode encodes a page number between 0 and 31. That's the base address for your call. The trap call always goes to offset zero of "its" page.

So if your goal is to write an instruction handler for "Trap5", you need to put a subroutine into page 5, starting at the first byte.

Page 0 is special: the instruction "trap0" (call page 0) as a side-effect sets the "busy" flag of the computer for reasons explained in the section on interrupts. As a general rule, while you're in page 0, or if the busy flag is on, you can't be interrupted, even if you didn't get there running "trap0": it's your safe zone.

In regular call-return type instructions (Call, COR, RTS), the base pointer (B:O) is used for saving and restoring the return address. But during trap calls and interrupts, the amenity pointer IA (Interrupt address) is used (we explained this in the section on BOPS), and you must use **RTI** (Return from Interrupt) to return from a trap or interrupt service routine. The advantage of this is that your trap or interrupt is completely transparent to the caller. Using trap instruction you can really build new, fully independent instructions.

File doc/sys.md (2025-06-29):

### SYS

Finally!, the last little block of instructions, the SYS group.
There are only 8 of them: NOP, SSI - SSO, SCL - SCH, RTS - RTI, and COR.
Let's go through them systematically.

#### NOP (No operation)

Here, the computer just sits pretty and passes its turn for one cycle. It's opcode is zero, so this is something like the "default" instruction.

#### Serial Port Control

The next four are for serial communication. In another document, there is a whole section on serial communication. But the basics are very simple.

When you transmit or receive over a serial data line, which is literally a wire, it goes just one bit at a time. So you put your data bit of electricity - low or high level voltage, 0 or 1 - on the line, so that the receiver can sample your data: is it a zero or a one bit?

###### Clock

Now that the received knows which kind of bit you sent, a good way for her to let you know know that she has read your bit and is ready for the next, is to use a second wire, the "clock" line.

Just like you have put a data bit on your line, your partner now puts a "tick" on the clock line. For example: low, then high, then low again. This is an encoded message to you! It says: I'm done with your data bit.
 
Then you - the sender - detect that tick on the clock line and send your next data bit. Rinse and repeat, that's all there is to it.

Apart from the clock line, this computer uses two data lines, one for input, one for output.
 
#### SCL - SCH (Set Serial Clock Low / High)

These two instructions are for controlling the state of the clock line. When you say SCL, the clock signal is set to "low" (0) and when you say SCH, the clock line is set to "high" (1). 

Now we need to figure out a way to convert a byte into a series of bits and vice-versa. There are two registers in this computer which do that: SIR and SOR.
 
#### SSI (Shift Serial Bit In)
 
SIR is the Serial Input Register. One bit of it is connected to the serial input wire, and it has what is called a shift register.

Every time you say "SSI", the bit that is on the serial input line is shifted into SIR at the lowest bit position, pushing out its highest order bit into nothing.

So with every "SSI" instruction you execute, the SIR is slowly filling up with bits, one by one, until 8 of them have been read in. Since 8 bits are all that the SIR can hold, if you execute more SSIs than that, the first bits that you shifted in will be "pushed out" of the shift register and you would be losing them.

So the sensible thing after 8 SSI instructions is to read out the SIR and store your data byte somewhere. You can do this with a pair instruction like SD (store SIR into D).
 
Also, you in between issuing the SSI instructions, you should also tick the clock-line using SCL and SCH as we said, to synchronise your partner.
  
#### SSO (Shift Serial Bit Out)
 
SSO is the Serial Output Register. Just like the SIR is converting bits into bytes, the SOR is turning bytes into bits.
 
For this to work, you store a byte into the SOR with a pair instruction like DS (store D into SOR). Then you do 8 SSO instructions, and with each of them, the current high-order bit of SOR gets shifted out onto the serial output line, the low order places slowly filling with zeros.

Also, you in between issuing the SSI instructions, you should also tick the clock-line using SCL and SCH as we said, to synchronise your partner.

#### RTS (Return from Subroutine)

This instruction reverses a call instruction. RTS increments L, so that the caller will have his local page back. Then it puts whatever is in B into C, and whatever is in O into PC. So the base pointer (B:O) had better point to the exact address you need to return to, because the next instruction is going to be fetched from there.

#### RTI (Return from TRAPs and Interrupts)

RTI (Return from Interrupt) is similar in operation but "clears the BUSY flag".

Let's explain this in a little more detail: As long as this flag is set, the computer will not accept an interrupt. An interrupt, when it is accepted by the computer, is literally a "Trap0" instruction that you can't predict will happen!

The computer - without you knowing - makes you run a call to an "interrupt service routine", and in the process, it sets the BUSY flag.

In contrast to RTS, trap calls, interrupts (same as Trap0!) and RTI do **not** use B:O to store the return address. And since they don't alter your base pointer, if the trap handler does a good job, you will be returned to where you left off to exactly the same state you were in and not notice a thing.

Traps and RTS use the amenity pointer "IA" (Interrupt Address), to store and retrieve the return address, instead of the base-pointer.

#### COR

COR stands for "Coroutine". This word should always be in the plural, since when you are using COR, you become the coroutine of another subroutine, and you are its coroutine.

COR puts whatever is in the base pointer (B:O) into C:PC, but keeps a copy (the return address) before overwriting these registers. Then, just before the jump, it overwrites the base pointer with the return address, so your coroutine knows where you left off.

The idea is that you both do your thing, taking turns: you jump to the coroutine, it does a bit of work, jumps backs to you, you do a bit of work and so on.

This instruction acts very much like a call/return, but without changing local pages. Of course you can also just use it as a jump to a 16-bit address.

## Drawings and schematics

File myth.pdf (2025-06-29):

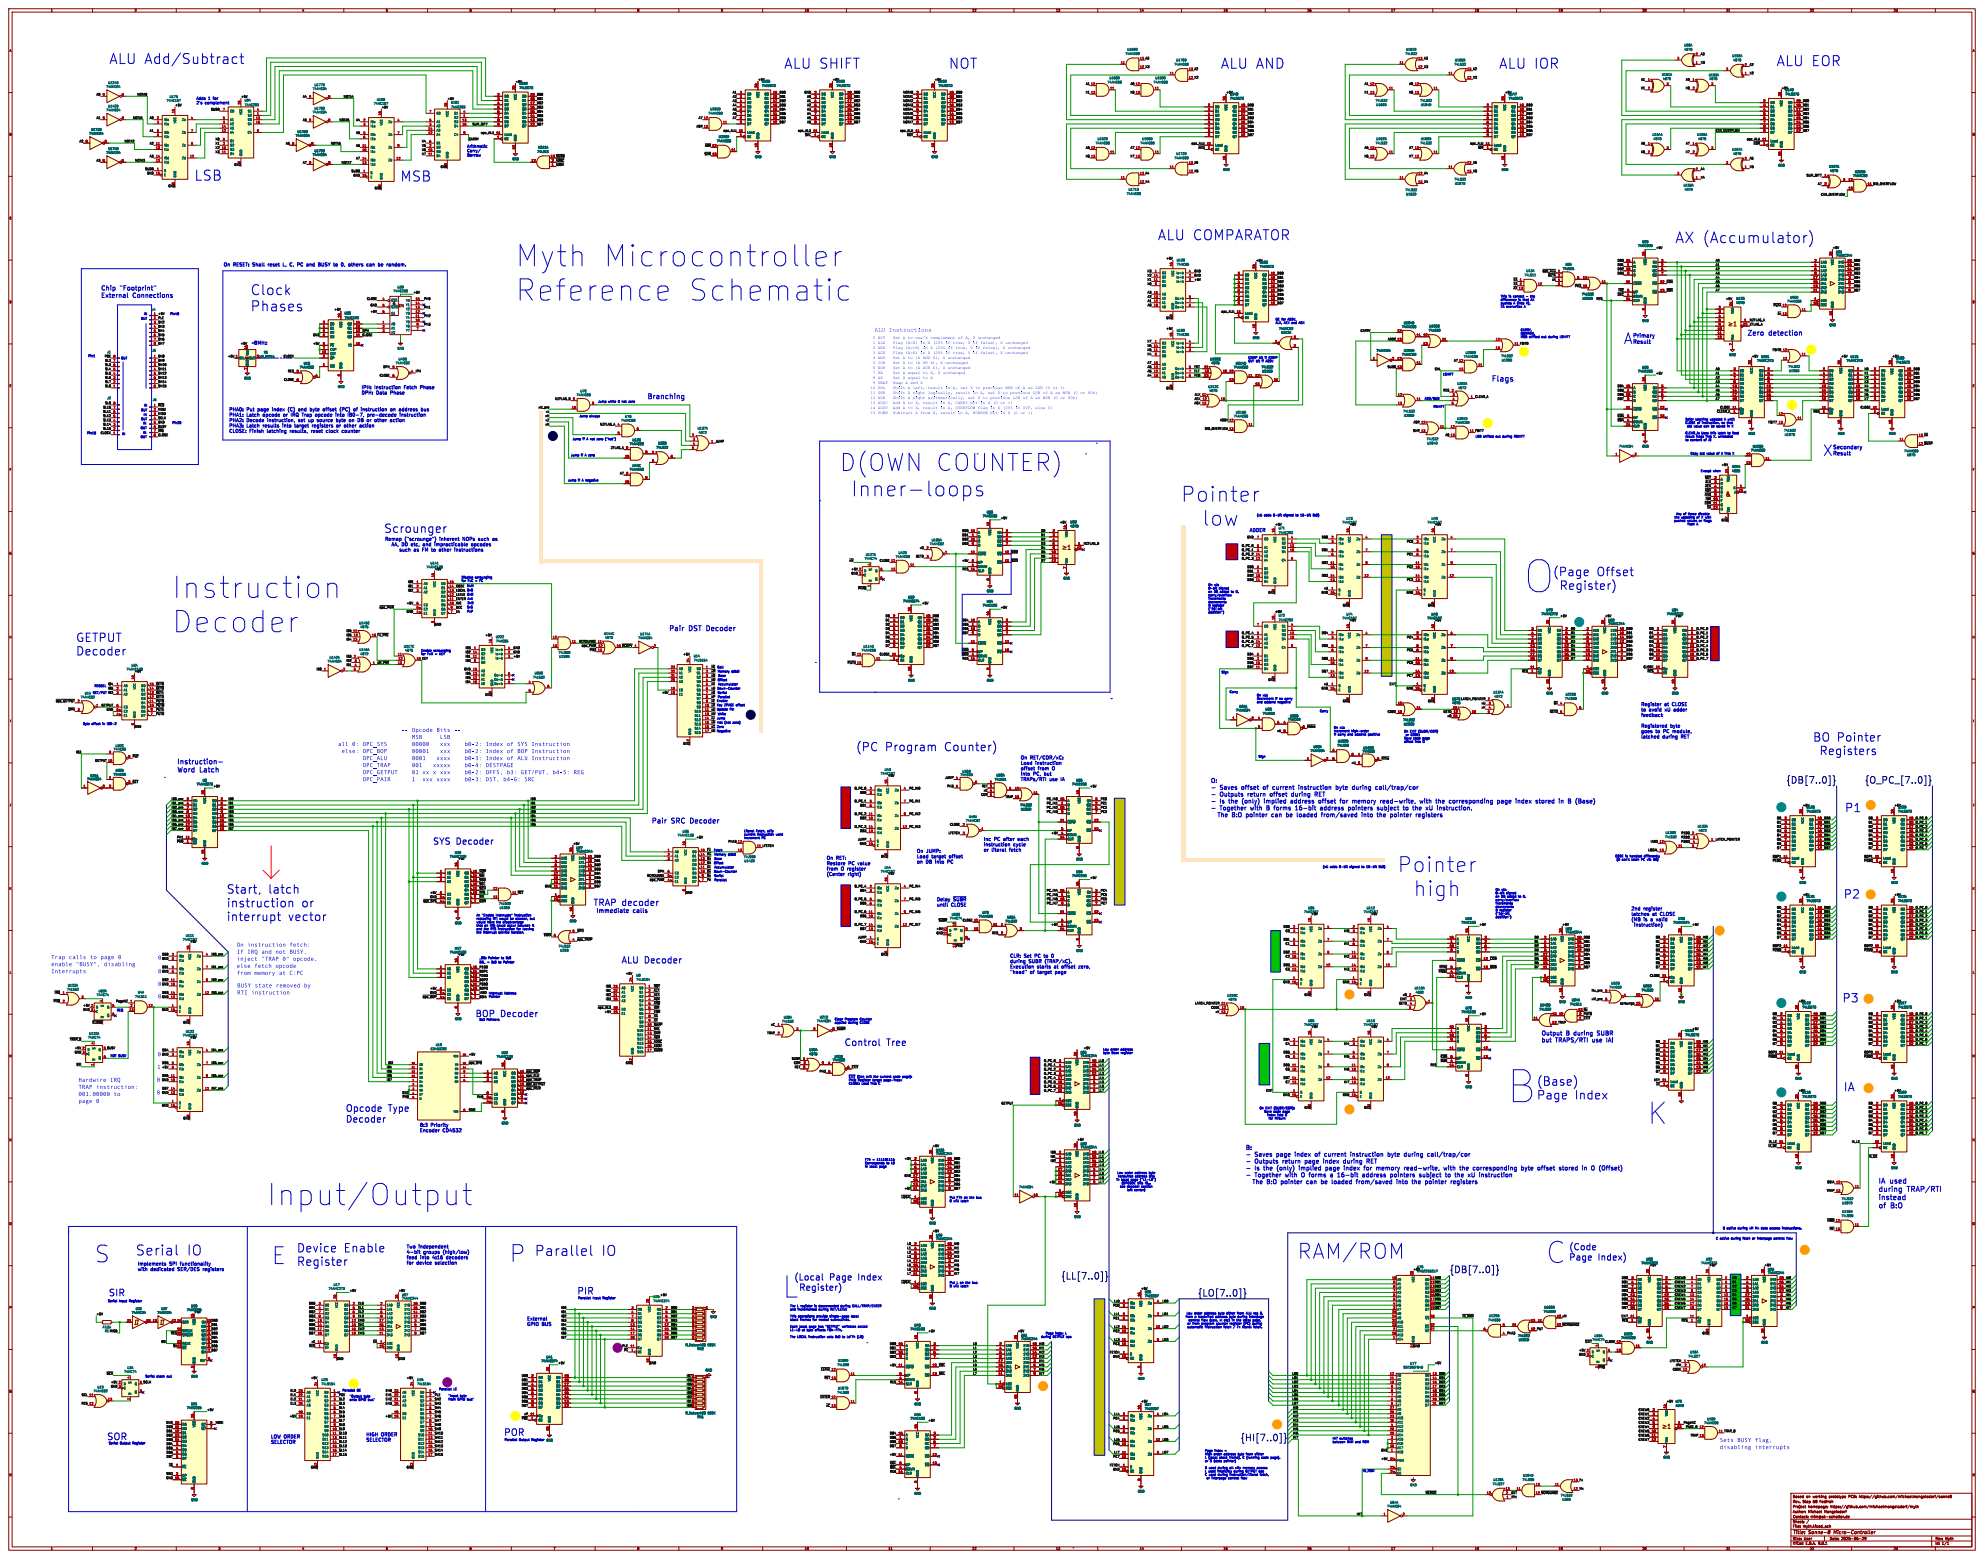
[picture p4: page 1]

COMP bit if COMP OVF bit if ADDV D(OWN COUNTER)

Jump while D not zero

Jump if A not zero ("hot")

such as FM to other instructions
AxA þÿ!“
Decoder

Down-Counter Accumulator Base Pair SRC Decoder

Clear Program Counter applied during CLOSE

~{EXIT}(Can exit the current code page): PH3: Register target page-index CLOSE: Load into C

B active during xM Mx data access instructions. Low order address byte either from ALU reg B,

Put L on the bus B will latch
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

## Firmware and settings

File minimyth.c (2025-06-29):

#include <stdio.h>
#include <stdlib.h>

/*
** Minimal C program as reference on how Myth CPU is intended to work.
** Use in conjunction with Verilog file and KiCad schematics.
** Project files see: https://github.com/michaelmangelsdorf/myth
** Author: 2025 Michael Mangelsdorf <mim@ok-schalter.de>
*/

/*
** CPU STATE VARIABLES
*/

/* Memory */

uint8_t ram[256][256] = {}; /* Organised as [PAGE-INDEX][BYTE-OFFSET] */

/* Interrupts */

uint8_t irq;   /* Interrupt Request Flag (input) */
uint8_t busy;  /* BUSY / Interrupts-Disabled flag (output) */

/* IO Device Selection */

uint8_t e_old; /* Device Enable Register */
uint8_t e;     /* _old is for persisting edge information in VM file */

/* Serial Interface */

uint8_t sclk;  /* SPI Serial Clock signal (output)  */
uint8_t miso;  /* SPI Master-in Slave-out bit (input) */
uint8_t mosi;  /* SPI Master-out Slave-in bit (output) */
uint8_t sir;   /* Serial Input Register */
uint8_t sor;   /* Serial Output Register */

/* GPIO bus */

uint8_t pir;   /* Parallel Input Register */
uint8_t por;   /* Parallel Output Register */

/* Accumulator and ALU*/

uint8_t a;     /* Primary Result (ALU input operand A) */
uint8_t x;     /* Secondary Result (ALU input operand X) */

/* Execution Control */

uint8_t c;     /* CODE Program Current Page-Index Register */
uint8_t pc;    /* Program-Counter Current Page-Offset Register */

/* 16-bit Base Pointer */

uint8_t b;     /* Base Page-Index Register */
uint8_t o;     /* Base Page-Offset Register */

/* 16-bit Amenity Pointers - Transfer to/from Base Pointer (B:O) */

uint8_t p1b, p1o; /* Page-index, page-offset parts */
uint8_t p2b, p2o;
uint8_t p3b, p3o;
uint8_t iab, iao;

/* Amenity Page-Index */

uint8_t k;

/* Local Stack Frame-Pointer */

uint8_t l;     /* Local Page Index Register */

/* Hardware Loop Counter */

uint8_t d;     /* Down-Counter / Auto-Decrement Register */


/*
** PROTOTYPES
*/

       void    myth_step();

static uint8_t fetch();

static void    push_acc( uint8_t v);
static uint8_t srcval(   uint8_t srcreg);
static uint8_t scrounge( uint8_t opcode);
static void    pair(     uint8_t opcode);
static void    getput(   uint8_t opcode);
static void    trap(     uint8_t opcode);
static void    alu(      uint8_t opcode);
static void    bop(      uint8_t opcode);
static void    sys(      uint8_t opcode);

static void    call(     uint8_t dstpage);


/* Single-step 1 instruction cycle
*/
void
myth_step()
{

/*  Decoding Schema:  -- Opcode Bits --
                         MSB     LSB
    all 0: OPC_SYS       00000   xxx    b0-2: Index of SYS Instruction
     else: OPC_BOP       00001   xxx    b0-2: Index of BOP Instruction
           OPC_ALU       0001   xxxx    b0-3: Index of ALU Instruction
           OPC_TRAP      001   xxxxx    b0-4: DESTPAGE
           OPC_GETPUT    01 xx x xxx    b0-2: OFFS, b3: GET/PUT, b4-5: REG
           OPC_PAIR      1  xxx xxxx    b0-3: DST, b4-6: SRC
*/

        uint8_t opcode;

        /* Before each instruction, Myth checks if an interrupt is
           requested. Such requests are ignored unless the BUSY flag
           is disabled AND the program is not executing in page 0.
           This latter condition assures that the system is not
           forced to interrupt while initialising upon RESET.

           If an interrupt is not ignored, the way it is handled
           is by injecting a "fake" opcode: A trap subroutine call to
           a service handler at page 0.
           During RESET, the local-page index register L is reset to 0,
           and this setting can be used to distinguish a RESET from
           an interrupt (instruction LOCAL).

           Executing a TRAP0 call from your program is indistinguishable
           from accepting an interrupt.
           Execute RTI to disable the busy flag and unnest the call. */

        if (irq && c!=0 && !busy) opcode = 32; /* Inject TRAP0 */
        else opcode = fetch();

        /*Decode priority encoded opcode
         and execute decoded instruction*/
        if      (opcode & 0x80) pair(   opcode);
        else if (opcode & 0x40) getput( opcode);
        else if (opcode & 0x20) trap(   opcode);
        else if (opcode & 0x10) alu(    opcode);
        else if (opcode & 0x08) bop(    opcode);
        else                    sys(    opcode);
}


/* Fetch next byte in CODE stream, then increment PC.
   Fetches either an instruction, or an instruction literal (Fx)
*/

uint8_t
fetch()
{
        return ram[c][pc++];
}


/* Coroutine Call - Similar to a function call but does not
   create a stackframe and allows target offsets other than 0.
   Jump to address in pointer B:O, then save return address in B:O */

void
cor()
{
        uint8_t temp;

        temp = o;
        o = pc;     /* Save page offset of return instruction */
        pc = temp;  /* Set branch target offset */

        temp = b;
        b = c;      /* Save page index of return instruction */
        c = temp;   /* Set branch target page-index */
}

/* Subroutine call (xC or TRAP) */

void
call( uint8_t dstpage)
{
        o = pc;      /* Save page offset of return instruction */
        pc = 0;      /* Always branch to page head: offset 0*/

        b = c;       /* Save page-index of return instruction */
        c = dstpage;

        l--;         /*Create stack frame*/
}


void
trap( uint8_t opcode)
{
        uint8_t dstpage = opcode & 31; /* Keep low order 5 bits only */
        if (dstpage==0) busy = 1;      /* Unique side-effect of TRAP0 */
       
        iao = pc;      /* Save page offset of return instruction */
        pc = 0;      /* Always branch to page head: offset 0*/

        iab = c;       /* Save page-index of return instruction */
        c = dstpage;
}


/* First step of handling PAIR instructions,
   derives the source value
*/

uint8_t
srcval( uint8_t srcreg)
{
/* PAIR Instruction - Bits 4-6: SOURCE index
   'SRCx' notation: Transfer SRC into DESTINATION x
   EFFECT means: Transfer has side effects:
   e.g.: M: Read from M, transfers value at B:O in memory to X
*/

#define Fx 0 /* FETCH literal (EFFECT: Get code-stream literal, advance PC) */
#define Mx 1 /* MEMORY @ B:O (EFFECT load a byte from memory as source) */
#define Bx 2 /* BASE Register */
#define Ox 3 /* OFFSET Register */
#define Ax 4 /* ACCUMULATOR Register */
#define Dx 5 /* DECREMENT Register */
#define Sx 6 /* SERIAL input */
#define Px 7 /* PARALLEL input */

        uint8_t pc0 = pc;
        switch(srcreg){
                case Fx: return fetch();
                case Mx: return ram[b][o];
                case Bx: return b;
                case Ox: return o;
                case Ax: return a;
                case Dx: return d;
                case Sx: return sir;
                case Px: return pir;
                default: return 0;
        }
}


/* Second part of handling PAIR instructions,
   stores source value into destination
*/
void
pair( uint8_t opcode)
{
        if (scrounge( opcode)) return;

/* PAIR Instruction - Bits 0-3: DESTINATION index
   'xREG' notation: Transfer SOURCE x into DEST
   EFFECT means: Transfer has side effects:
   e.g.: CALL: Write into C, calls C:0, stores return pointer in B:O
*/

#define xC 0  /* CALL (EFFECT: subroutine call)*/
#define xM 1  /* MEMORY @ B:O (EFFECT: Store source into memory at B:O) */
#define xB 2  /* BASE Register */
#define xO 3  /* OFFSET Register */
#define xA 4  /* ACCUMULATOR Register (EFFECT: Saves old value of A in X) */
#define xD 5  /* DECREMENT Register */
#define xS 6  /* SERIAL output */
#define xP 7  /* PARALLEL output */
#define xE 8  /* ENABLE Register (EFFECT: Sets hardware select signals) */
#define xK 9  /* KEY Register */
#define xU 10 /* UPDATE (Effect: Adds signed byte to 16-bit pair B:O) */

/* The following are all EFFECT instructions (JUMPS) */

#define xW 11 /* WHILE D - Write into PC WHILE D is not zero, decrement D */
#define xJ 12 /* JUMP - Writes into pc */
#define xH 13 /* JUMP IF HOT (NOT ZERO) - Write into PC if A is not zero*/
#define xZ 14 /* JUMP IF ZERO - Write into PC if A is zero */
#define xN 15 /* JUMP IF NEGATIVE - Write into PC if A has bit 7 set */

        uint8_t src = (opcode >> 4) & 7; /* Zero except bits 4-6 at LSB */
        uint8_t dst = opcode & 15;       /* Zero except bits 0-3 at LSB */
        uint8_t v = srcval(src);
        uint16_t ui16;

        switch(dst){
                case xC: call(v);           break;
                case xM: ram[b][o] = v;     break;
                case xB: b = v;             break;
                case xO: o = v;             break;
                case xA: push_acc(v);       break;
                case xD: d = v;             break;
                case xS: sor = v;           break;
                case xP: por = v;           break;
                case xE: e_old = e;
                         e = v;             break;
                case xK: b = k; o = v;      break;

                 /* Add signed 8-bit v to 16-bit B:O */

                case xU: ui16 = (o+v)>127? /* Sign extend to 16-bit */
                                 (uint16_t)v | 0xFF00 : v;
                         o = ui16 & 0xFF;
                         b = ui16 >> 8;
                         break;

                case xW: if (d) pc = v;
                         d--; /*Post decrement, either case!*/
                         break;
                case xJ: pc = v;            break;
                case xH: if (a) pc = v;     break;
                case xZ: if (!a) pc = v;    break;
                case xN: if (a&128) pc = v; break;
        }
}


uint8_t
scrounge( uint8_t opcode)
{

/*Scrounged Pairs - Repurpose/remap "diagonal" NOP instructions */

#define KEY   16*Fx + xM /* Remaps FM instruction to KEY */
#define CODE  16*Mx + xM /* and so forth */
#define LOCAL 16*Bx + xB
#define LEAVE 16*Ox + xO
#define ENTER 16*Ax + xA
#define INC   16*Dx + xD
#define DEC   16*Sx + xS
#define EA    16*Px + xP

        switch(opcode & 0x7F){
                case KEY:      k=b;                return KEY;
                case CODE:     b=c; o=pc;          return CODE;
                case LOCAL:    b=l; o=0xF7; /*L0*/ return LOCAL;
                case LEAVE:    l++;                return LEAVE;
                case ENTER:    l--;                return ENTER;
                case INC:      a++;                return INC;
                case DEC:      a--;                return DEC;
                case EA:       push_acc(e);          return EA;
                default: return 0;
        }
}


void push_acc(uint8_t v){
        x = a;
        a = v;
}


/* Execute GETPUT instruction
*/

void
getput( uint8_t opcode)
{
#define GETPUT_OFFSET 0xF8 /*Local-page offset*/

        /* Opcode BIT 3 encodes GET/PUT mode */
        #define BIT3 8

        /* Opcode BITS 4-5 encode register index (BOAD) */
        #define BITS45 (opcode >> 4) & 3
        
        /* Opcode BITS 0-2 encode address offset in local page (from F8h) */
        #define BITS02 opcode & 7

        uint8_t index = BITS02;
        uint8_t *mptr = &( ram[l][GETPUT_OFFSET +index] );

        if(opcode & BIT3)
                switch(BITS45){
                        case 0: *mptr = b; break;
                        case 1: *mptr = o; break;
                        case 2: *mptr = a; break;
                        case 3: *mptr = d; break;
                }
        else
        switch(BITS45){
                case 0: b = *mptr;       break;
                case 1: o = *mptr;       break;
                case 2: push_acc(*mptr); break;
                case 3: d = *mptr;       break;
        }
}


/* Execute ALU instruction
*/
void
alu( uint8_t opcode)
{

/*ALU Instructions */

#define NOT   0 /* Set A to one's complement of A , X unchanged */
#define ALX   1 /* Flag (A<X) in A (255 if true, 0 if false), X unchanged */
#define AEX   2 /* Flag (A==X) in A (255 if true, 0 if false), X unchanged */
#define AGX   3 /* Flag (A>X) in A (255 if true, 0 if false), X unchanged */
#define AND   4 /* Set A to (A AND X), X unchanged */
#define IOR   5 /* Set A to (A OR X), X unchanged */
#define EOR   6 /* Set A to (A XOR X), X unchanged */
#define XA    7 /* Set A equal to X, X unchanged */
#define AX    8 /* Set X equal to A */
#define SWAP  9 /* Swap A and X */
#define SHL  10 /* Shift A left, result in A, set X to previous MSB of A as LSB (0 or 1) */
#define SHR  11 /* Shift A right logically, result in A, set X to previous LSB of A as MSB (0 or 80h) */
#define ASR  12 /* Shift A right arithmetically, set X to previous LSB of A as MSB (0 or 80h) */
#define ADDC 13 /* Add A to X, result in A, CARRY bit in X (0 or 1) */
#define ADDV 14 /* Add A to X, result in A, OVERFLOW flag in X (255 if OVF, else 0) */
#define SUBB 15 /* Subtract A from X, result in A, BORROW bit in X (0 or 1) */

        uint8_t a0 = a;

        /* Compute signed addition overflow flag */
        int i = x+a;
        uint8_t ovf = ((a&0x80)^(x&0x80))==0    /* Addends have same sign */
                        && ((i&0x80)^(a&0x80)); /* But result has different sign */
        
        switch(opcode & 15){
                case NOT: a = ~a;                                       break;
                case ALX: a = (a<x)  ? 255:0;                           break;
                case AEX: a = (a==x) ? 255:0;                           break;
                case AGX: a = (a>x)  ? 255:0;                           break;
                case AND: a = a & x;                                    break;
                case IOR: a = a | x;                                    break;
                case EOR: a = a ^ x;                                    break;
                case XA: a=x;                                           break;
                case AX: x=a;                                           break;
                case SWAP: a=x; x=a0;                                   break;
                case SHL: a<<=1; x=(a0 & 0x80)? 1:0;                    break;
                case SHR: a>>=1; x=(a0 & 1)? 0x80:0;                    break;
                case ASR: a=(a>>1)+(a0 & 0x80); x=(a0 & 1)? 0x80:0;     break;
                case ADDC: a=i&0xFF; x=(i>255)? 1:0;                    break;
                case ADDV: a=i&0xFF; x=ovf?255:0;                       break;
                case SUBB: i = x - a;
                           a = x - a;
                           x = (i<0) ? 1 : 0;
                 break;
        }
}


/* Execute BOP instruction
*/
void
bop( uint8_t opcode)
{
                /*BOP Instructions */
#define P1BO 0 /* Store POINTER into B:O */
#define BOP1 1 /* Store B:O into POINTER */
#define P2BO 2 
#define BOP2 3
#define P3BO 4 
#define BOP3 5
#define IABO 6 
#define BOIA 7

        switch(opcode & 7){
                case P1BO: b=p1b; o=p1o; break;
                case BOP1: p1b=b; p1o=o; break;

                case P2BO: b=p2b; o=p2o; break;
                case BOP2: p2b=b; p2o=o; break;
                
                case P3BO: b=p3b; o=p3o; break;
                case BOP3: p3b=b; p3o=o; break;
                
                case IABO: b=iab; o=iao; break;
                case BOIA: iab=b; iao=o; break;
        }
}


/* Execute SYS instruction
*/
void
sys( uint8_t opcode)
{
                /*SYS Instructions */
#define NOP 0 /* No Operation */
#define SSI 1 /* Serial Shift In */
#define SSO 2 /* Serial Shift Out */
#define SCL 3 /* Set serial Clock Low */
#define SCH 4 /* Set serial Clock High */
#define RTS 5 /* Return from Subroutine */
#define RTI 6 /* Return from Interrupt */
#define COR 7 /* Coroutine: Jump to B:O, save return pointer in B:O */

        switch(opcode & 7){ /*Zero except low order 3 bits*/
                case NOP: break;
                case SSI:
                        /*Clocks in MISO line bit into LSB*/
                        sir = (sir<<1) + miso;
                        break;
                case SSO:
                        /*Clocks out MOSI MSB first*/
                        mosi = sor & 0x80 ? 1:0;
                        sor <<= 1;
                        break;
                case SCL: sclk = 0; break;
                case SCH: sclk = 1; break;
                case RTI:
                        busy = 0;
                        c = iab;
                        pc = iao;
                        l++; /* Leave stack frame*/
                        break;
                case RTS:
                        c = b;
                        pc = o;
                        l++; /* Leave stack frame*/
                        break;
                case COR: cor(); break;
        }
}


int
main(int argc, char *argv[])
{
        // RESET: Set L, C, PC and BUSY to 0
        // Run myth_step() n times
        printf("Myth CPU Implementation Stub\n");
        exit(0);
}

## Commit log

2025-06-01 Start with pseudo-"schematics"
    Bring over schematics as reference from parent project.
    [myth.kicad_sch]
2025-06-02 Clean schematics, add SYS_IO opcode group
    [myth.kicad_sch]
2025-06-03 Try create IPC counter
    [myth.kicad_sch]
2025-06-03 Add interrupt logic
    [myth.kicad_sch]
2025-06-03 Fix memory output enable
    [myth.kicad_sch]
2025-06-03 Fix bus name
    [myth.kicad_sch]
2025-06-04 Fix bugs and change interrupts
    [myth.kicad_sch]
2025-06-04 Redesign ALU, add BOPs
    [myth.kicad_sch]
2025-06-04 Clean up schematics
    [myth.kicad_sch]
2025-06-04 Add IOK instruction
    [myth.kicad_sch]
2025-06-04 Move IOK to RTI instruction, identical to RET
    [myth.kicad_sch]
2025-06-04 Name P4 stack pointer
    [myth.kicad_sch]
2025-06-04 Change incorrect signal label
    [myth.kicad_sch]
2025-06-04 Rename RET to RTS, to match RTI
    [myth.kicad_sch]
2025-06-04 Fix floating pins in scrounger
    [myth.kicad_sch]
2025-06-05 Fix comments in schematics
    [myth.kicad_sch]
2025-06-05 Reformat IO section
    [myth.kicad_sch]
2025-06-05 Various fixes, change CODE/LOCAL to supply pointers
    [myth.kicad_sch]
2025-06-05 Update schematics PDF
2025-06-05 Fix bug in ALU
    [myth.kicad_sch]
2025-06-05 Document ALU section
    [myth.kicad_sch]
2025-06-05 Add reference implementation to complement schematics
2025-06-05 Fix GO, move to COR
    [myth.kicad_sch]
2025-06-05 Add JUMP if negative
    [myth.kicad_sch]
2025-06-06 Add xR
    [myth.kicad_sch]
2025-06-06 Add spec doc
    [myth.kicad_sch]
2025-06-06 Change BOP3 to named pointer
    [myth.kicad_sch]
2025-06-07 Clarify xR instruction in spec
    [myth.kicad_sch]
2025-06-07 Rename INC/DEC INCA/DECA for clarity
    [myth.kicad_sch]
2025-06-07 Change CAR instruction to OVF combo
    [myth.kicad_sch]
2025-06-07 Rename BOPS format group
    [myth.kicad_sch]
2025-06-07 Fix comments in schematics file
    [myth.kicad_sch]
2025-06-08 Reorder regs, change xR instruction, update docs
    [myth.kicad_sch]
2025-06-08 Fix bug in schematics
    [myth.kicad_sch]
2025-06-08 Add comments to ALU section
    [myth.kicad_sch]
2025-06-08 Shorten BOP mnemonics
    [myth.kicad_sch]
2025-06-08 Add opcode specs file
    [myth.kicad_sch]
2025-06-09 Add Verilog sketch
    [myth.kicad_sch]
2025-06-10 Change CODE instruction and interrupt behaviour
    [myth.kicad_sch]
2025-06-11 Change ALU
    [myth.kicad_sch]
2025-06-11 Update Verilog sketch for new ALU
    [myth.kicad_sch]
2025-06-12 Improve ALU
    [myth.kicad_sch]
2025-06-12 Clean up C code
    [myth.kicad_sch]
2025-06-12 Clarify that only TRAP 0 sets BUSY as side-effect
    [myth.kicad_sch]
2025-06-12 Add schematics .png for readme.md
2025-06-12 Update README.md add .png file of schematics
2025-06-12 Comment regarding RTI vs. EIN
    [myth.kicad_sch]
2025-06-13 Change mnemonics for BOP transfers
    [myth.kicad_sch]
2025-06-14 Clean up schematics, rename BOP registers
    [myth.kicad_sch]
2025-06-14 Rename BO pointers
    [myth.kicad_sch]
2025-06-14 Fix displaced wire in schematics
    [myth.kicad_sch]
2025-06-15 Document BOP registers, fix spec
    [myth.kicad_sch]
2025-06-17 Fix chip footprint in schematic
    [myth.kicad_sch]
2025-06-17 Change controller name
    [myth.kicad_sch]
2025-06-17 Add example code to readme.md
    [myth.kicad_sch]
2025-06-18 Fix bug in C ref implementation
    [myth.kicad_sch]
2025-06-18 Fix bug in C ref of ALU
    [minimyth.c]
2025-06-21 Add assembler
2025-06-22 Fix lots of bugs
    [cpu.c]
2025-06-23 Fix bugs, write divmod
    [cpu.c, minimyth.c]
2025-06-23 Fix incorrect buffer addresses in spec
    [cpu.c]
2025-06-25 Fix bug in EA instruction
    [minimyth.c]
2025-06-25 Fix bug in EA instruction.
    [cpu.c]
2025-06-29 Change trap/interrupt logic
    [myth.kicad_sch]
